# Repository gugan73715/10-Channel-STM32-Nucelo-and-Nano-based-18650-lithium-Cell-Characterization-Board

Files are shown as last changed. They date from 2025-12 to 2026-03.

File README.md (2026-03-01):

# Cell Characterization Board V1.2
This project is a 10-channel sequential lithium-ion cell (18650) characterization instrument designed to measure cell voltage, discharge current, internal resistance, and capacity under a controlled constant-current load of up to 5 A. The Cell data would be displayed on an LCD and stored on a MicroSD card which can be used to plot discharge curves using Excel/Matlab/Python. Protection features include Reverse Polarity Protection for each channel, Low voltage cut-off and hardware controlled sequential switching circuit with hardware interlock to create mutually exclusive channels.

V1.2 serves as a validation vehicle for the custom analog front-end and discharge bus, utilizing a modular MCU architecture (Nucleo/Nano) to minimize BOM and assembly costs as well as accelerate testing. Planned V2 would be an integrated STM32G0B1CCT6 based revision with a SPI TFT display.

## Primary Use Case

This system is designed to characterize and screen individual lithium-ion cells prior to adding it into a battery pack for UBC Rocket's Cloudburst rocket. This allows to exclude defective, mismatched, or degraded cells before battery pack assembly. It also helps prevent cell imbalance in series strings, individual cells overheating during discharge and reduced pack capacity due to lower cell capacity. This device could also be used in other projects involving high-energy battery systems such as Student Formula SAE electric vehicles, solar car teams, and any project requiring testing and characterization of large numbers of lithium-ion cells prior to pack assembly. 

## Key design goals
- Programmable constant-current discharge
- Accurate, ratiometric voltage and current measurement
- Fault-tolerant handling of reverse polarity and missing cells
- Sequential testing to minimize BOM cost and thermal complexity
- Hardware based protection features for reliability
- Reduce manufacturing and assembly cost as much as possible due to budget constraint
- Rapid bring up
- Clear documentation of design intent and constraints
  
# PCB Design:
## Latest 3D Render:
Cell Characterization Board V1 2 3D Render - Top
Cell Characterization Board V1 2 3D Render - Bottom
## V1.2:


## System Validation & Discharge Data:
CELL ID 3
Full discharge curve of a Sony VTC4 cell generated using the cell data from V1.2 10-channel tester, ploted using MATLAB. The system maintained a stable 1.5A constant current discharge, yielding a capacity measurement that matched the manufacturer's datasheet within 5% and a DCIR of 33mohm. This data confirms the precision of the op-amp control loop over a full discharge cycle and MOSFET maintained a approximate 45-50C temperature.

## Overview:
The system is implemented on a custom 4-layer mixed-signal PCB (SIG / GND / PWR / SIG) optimized for high-current power handling, precision analog measurement and noise handling. GND and PWR plane are continuous and unbroken providing low-impedance return paths and a stable reference plane. Proper zoning (Analog/Digital/Power) based component placement for noise immunity and short traces. Cell holders and relays are placed on both sides to decrease PCB size which helps reduce PCB manufacturing cost.
### High-Current Routing
- All >2 A paths use wide copper pours with stitching vias if possible to distribute the current
- All high current paths are kept as far away as possible from sensitive analog traces

### Analog Integrity
- All analog traces are on top layer with a GND plane below them
- Analog traces are kept as short as possible
- Important analog signals are buffered and have a decoupling capacitor close to it
- Quasi-Kelvin sense (Separate PWR and SIG traces but shared GND) is used for current and voltage measurement
  
### Noise and Protection
- Relay drive and switching currents are physically separated from the analog front-end
- External flyback diodes placed adjacent to each relay
- Relay coil and Flyback traces are kept as short as possible and fanned out to prevent noise from adjacent traces
- Decoupling capacitors placed close to each IC supply pin
- Reverse polarity protection for each channel using P-channel MOSFETs
- V_Cell traces are connected straight to cell holder for Quasi-kelvin sense and current limiting resistor on each trace to protect the MUX in case of reverse polarity.
- NTC on Load MOSFET's heatsink for active over temperature protection
- 30 ms Soft start for BUCK IC to prevent overshoot and inrush current

### Debugging
- Testpoints for 5V, 3.3V, 2.5V ref, GND, I_set, Constant Current op-amp feedback line, MOSFET Gate and I_sense.
- External UART, SPI and I2C headers for logic analysis
- MUX-out(Cell voltage) is accessible through MCU header

### Assembly & Cost Optimization
- 5 channels were placed on top and bottom to reduce PCB size and save fabrication costs
- Passive components are assembled by fabrication house and all of them have been placed on top for one sided assembly
- Active ICs, cell holders and connectors are hand-assembled post-fabrication to reduce assembly cost while retaining full control over critical components

# Hardware
08e247f1-ca4d-435c-84c2-786f73447f0c-0

## System Architecture Summary (Click subsection header for schematic sheet)
<details>
<summary><h3>Buck and LDO</h3></summary>
  
Buck and LDO Schematic (https://github.com/user-attachments/assets/7cbbd1c2-d676-4704-b09d-97c5c336276e)
</details>

- input DC Jack / XT60: 8–40 V
- input USB-C: 5V 3A (Non-PD)
- 5 V logic rail via AP64502QSP-13 based synchronous buck converter
- Dedicated 3.3 V LDO for MicroSD and SPI

<details>
<summary><h3>Constant Current Sink</h3></summary>
  
Constant Current Sink (https://github.com/user-attachments/assets/1adb6a28-354b-4ce8-b8a3-19815ae03084)
</details>

- IRLZ44N Logic level MOSFET and TLV9162 control op-amp
- Low side 50mohm 3W shunt
- DAC60501ZDGSR 12-bit DAC for precise control of discharge current and controlled via I2C
- Internal 2.5 V precision reference of DAC is shared by ADC as well
- Amplified I_sense signal (0 - 2.5V) using MCP6001 for better resolution
- Theoretical MOSFET temperature with heat sink (θ_normal = 2.6 C/W) at max case (5A) is 115.86 C (Assuming 25 C ambient)
- Load MOSFET temperature monitoring via NTC
- Maximum discharge current: 5 A

<details>
<summary><h3>MCU</h3></summary>

MCU (https://github.com/user-attachments/assets/0a89f7f0-6815-4320-b8e9-275b107875d0)

</details>

- Compatible with 3.3V STM32 Nucleo boards with nano connectivity like NUCLEO-L432KC and Arduino nano
- External I2C header for debugging and future expansion modules
- External UART header for telemetry

<details>
<summary><h3>Cell Holder</h3></summary>

Cell Holder (https://github.com/user-attachments/assets/d6683df6-3a02-4f7b-97c8-28835414f6b9)

</details>

- DIY 3D printed SMD 18650 cell holders (similar to Keystone 1043) with 0.2mm nickel strips as cell contacts to save BOM cost
- Reverse polarity protection for each channel using MCQ7328-TP P-channel MOSFETs
- Cell voltage sense traces are connected straight to cell holder pads for quasi-kelvin sense

<details>
<summary><h3>Sequential Cell Switching</h3></summary>

Sequential Cell Switching (https://github.com/user-attachments/assets/1cc9c982-065a-40d1-963c-5ec4ebc452d4)

</details>

- Control Logic: MCU -> I2C Expander -> Line Decoder (For mutually exclusive channels) -> Relay Driver -> Relay -> Cell Holder
- Relay-based physical isolation of cells driven by darlington transistor array on High side
- PCF8575PWR I2C expander for I/O expansion
- CD4514BM96 decoder to prevent connecting more than one channel at the same time and an active high inhibit pin controlled by I2C expander
- External pull ups on all I2C lines and external flyback diodes on all relays

<details>
<summary><h3>Cell Monitoring</h3></summary>

Cell Monitoring (https://github.com/user-attachments/assets/edf4d94d-06c7-463c-b50f-4eb45057faaf)

</details>

- CD74HC4067SM96 16:1 analog MUX for cell voltage sampling
- MUX out is converted to a signal of 0 to 2.5V using a voltage divider and then buffered
- Current limiting resistor(limits to 2.1mA) on each channel to protect the MUX in case of reverse polarity (MUX's internal ESD clamp diode forward biases)

<details>
<summary><h3>MicroSD</h3></summary>

MicroSD (https://github.com/user-attachments/assets/78fb6a4d-2293-464c-a3f9-e3ed3d292f46)

</details>

- Data is written to MicroSD using SPI
- TXU0304PWR unidirectional voltage level translator for 5V to 3.3V for SCK, MOSI, CS (MCU to MicroSD) and 3.3V to 5V for MISO (MicroSD to MCU)
- SD detect LED for user-friendliness
- Parameters: Time, Cell Voltage, Discharge Current, Internal Resistance, I_set, Cut-off voltage and capacity (mAh / Wh)
- Internal Resistance is calculated using r = (V_OC - V_sense)/I. (Voltage drop across cell under a load)

## Prototyping and Validation:

### LTspice simulation: (Constant Current Sink)



### Breadboard prototyping:


- Constant current sink prototype built using IRL510 + LM158J
- Shunt resistor: 1.5 Ω / 5 W
- Gate and feedback resistors as implemented in hardware
- 0.5V out DAC emulated via resistive divider from 5 V
- Load driven by a current-limited (For safety) bench supply (2.5 V–4.2 V sweep)

Measured discharge current remained approximately constant (~340 mA) across the full input voltage range.

# Firmware

- Initial firmware developed using Arduino IDE for rapid bring-up
- Secondary firmware under development using STM32CubeIDE with STM32HAL and testing using an NUCLEO-G431KB

### Objectives:

- Validation of the sequential switching mechanism to guarantee mutual exclusivity of active channels
- Cell voltage sampling verification across all channels using the MUX
- Verify ADC and DAC resolution using the shared 2.5 V reference
- Validation of current measurement accuracy and stability across the full discharge range

# Planned Revision (V2):

- Transitioning to a STM32G0B1CCT6 onboard MCU
- Switching to SPI-based TFT display for real-time visualization
- Switching to Zero-drift, ultra-low-offset op-amp for better accuracy
- NTC on each channel for cell temperature monitoring
- Short-circuit and overtemperature protection for each channel 
- Firmware detection of protection features and informing the user
- Audible and visual fault and status indication (buzzer and status LEDs)

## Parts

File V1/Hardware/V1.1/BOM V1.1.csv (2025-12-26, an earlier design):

Line # | Name | Description | Designator | Quantity | Manufacturer 1 | Manufacturer Part Number 1 | Manufacturer Lifecycle 1 | Supplier 1 | Supplier Part Number 1 | Supplier Unit Price 1 | Supplier Subtotal 1
 | AP64502QSP-13 | Description | BUCK IC | 1 | Diodes Inc. | AP64502QSP-13 | Volume Production | Mouser | 621-AP64502QSP-13 | 3.56 | 3.56
 | CC0603KPX7R9BB104 | CAP CER 0.1UF 50V X7R 0603 | C1, C2, C3, C4, C12, C14, C15, C16, C17, C18, C19, C20 | 11 | Yageo Group | CC0603KPX7R9BB104 | Volume Production | Mouser | 603-CC603KPX7R9BB104 | 0.03796 | 0.41751
 | EEE-FT1H221GP | CAP ALUM 220UF 20% 50V SMD | C5 | 1 | Panasonic | EEE-FT1H221GP | Unknown | Arrow Electronics | EEE-FT1H221GP | 0.44956 | 0.44956
 | GRM155R61H474KE11D | Chip Multilayer Ceramic Capacitors for General Purpose, 0402, 0.47uF, X5R, 15%, 10%, 50V | C6, C7, C8, C9 | 4 | Murata | GRM155R61H474KE11D | Volume Production | Mouser | 81-GRM155R61H474KE1D | 0.05061 | 0.50607
 | CL31A106KBHNNNE | CAP CER 10UF 50V X5R 1206 | C10, C11 | 2 | Samsung Electro-Mechanics | CL31A106KBHNNNE | Volume Production | DigiKey | 1276-2876-6-ND | 0.12652 | 0.25304
 | C0402C103J3RACAUTO | C0402 10,000 pF X7R 5.00% 25 V | C13 | 1 | KEMET | C0402C103J3RACAUTO | Volume Production | Mouser | 80-C0402C103J3RAUTO | 0.14058 | 0.14058
 | S1M-13-F | Surface Mount Glass Passivated Rectifier, 1000V, 1 A, -65 to 125 degC, 2-Pin SMA Package, RoHS, Tape and Reel | D1, D2, D3, D4, D5, D6, D7, D8, D9, D10 | 10 | Diodes Inc. | S1M-13-F | Volume Production | DigiKey | S1M-FDIDKR-ND | 0.15604 | 1.56
 | DAC60501ZDGSR | True 12-bit, 1-ch, SPI/I2C, voltage-output DAC in WSON package with precision internal reference 10-VSSOP -40 to 125 | DAC | 1 | Texas Instruments | DAC60501ZDGSR | Volume Production | DigiKey | 296-DAC60501ZDGSRCT-ND | 3.77 | 3.77
 | PJ-102BH | Through Hole Right Angle DC Power Jack, 5 A, 2.5 mm Center Pin, 3 Position, -25 to 85 degC, RoHS, Bulk | DC JACK - IN | 1 | Same Sky | PJ-102BH | Volume Production
 | 74279252 |  | FB1 | 1 | Wurth Elektronik | 74279252 | Unknown | Mouser | 710-74279252 | 0.42173 | 0.42173
 | PCF8575PWR | Remote 16-Bit I2C and SMBus I/O Expander with Interrupt Output, 2.5 to 5.5 V, -40 to 85 degC, 24-pin TSSOP (PW), Green (RoHS & no Sb/Br) | I2C EXPANDER | 1 | Texas Instruments | PCF8575PWR | Volume Production | Arrow Electronics | PCF8575PWR | 1.59 | 1.59
 | TSW-104-23-T-S | CONN HEADER VERT 4POS 2.54MM | I2C, UART | 2 | Samtec | TSW-104-23-T-S | Volume Production | Avnet | TSW-104-23-T-S | 0.4684 | 0.9368
 | MGAH06036R8M-10 | 6.8 ÂµH Shielded Molded Inductor 5 A 50mOhm Max Nonstandard | L1 | 1 | Laird | MGAH06036R8M-10 | Volume Production | Mouser | 739-MGAH06036R8M-10 | 0.63259 | 0.63259
 | IRLZ44NPbF | MOSFET N-CH 55V 47A TO220AB | MOSFET_CC | 1 | Infineon | IRLZ44NPBF | Volume Production | Arrow Electronics | IRLZ44NPBF | 1.97 | 1.97
 | CD74HC4067SM96 | IC MUX/DEMUX 1X16 24SSOP | MUX | 1 | Texas Instruments | CD74HC4067SM96 | Volume Production | Mouser | 595-CD74HC4067SM96 | 0.88563 | 0.88563
 | NXRT15XH103FA1B030 | Thermistor NTC 10kΩ ±1% 2-Pin Radial Bulk | NTC | 1 | Murata | NXRT15XH103FA1B030 | End of Life | Arrow Electronics | NXRT15XH103FA1B030 | 0.19371 | 0.19371
 | TLV9162IDDFR | Dual, 16V, 11MHz, rail-to-rail input and output low-offset-voltage low-noise operational amplifier | OA CC SINK, OA UB 1 | 2 | Texas Instruments | TLV9162IDDFR | Volume Production | Mouser | 595-TLV9162IDDFR | 2.78 | 5.57
 | MCP6001UT-E/OT | None | OA I_SENSE, OA UB 2 | 2 | Microchip | MCP6001UT-E/OT | Volume Production | Farnell | 1840893 | 0.47585 | 0.95169
 | 2K2 5% 0402(1005) | 2K2 0.063W 5% 0402 (1005 Metric) SMD | R1 | 1 | Bourns | CR0402-JW-222GLF | Volume Production | Farnell | 4153652 | 0.00772 | 0.07716
 | 1K3 5% 2512(6432) | 1K3 1W 5% 2512 (6432 Metric) SMD | R2 | 1 | Vishay | CRCW25121K30JNEG | Volume Production | Arrow Electronics | CRCW25121K30JNEG | 0.16757 | 0.16757
 | CPF0603B10K7E | RES SMD 10.7KΩ 0.1% 1/16W 0603 | R3, R4 | 2 | TE Connectivity / AMP | 1-1879220-2 | Volume Production | Mouser | 279-CPF0603B10K7E | 0.43579 | 0.87157
 | Resistor 4k7 +/-1% 0402 100 mW | Chip Resistor, 4.7 KOhm, +/- 1%, 0.1 W, -55 to 155 degC, 0402 (1005 Metric) | R5, R8, RPU1, RPU2, RPU3, RPU4, RPU5, RPU6, RPU7, RPU8, RPU9, RPU10 | 12 | Panasonic | ERJ-2RKF4701X | Volume Production | Newark | ERJ2RKF4701X | 0.025 | 0.3
 | 523K 1% 0805(2012) | 523K 0.125W 1% 0805 (2012 Metric) SMD | R6 | 1 | Vishay | CRCW0805523KFKEA | Volume Production | Arrow Electronics | CRCW0805523KFKEA | 0.00295 | 0.00295
 | CRCW1210220RJNTA |  | R7 | 1 | Vishay | CRCW1210220RJNTA | Volume Production | Mouser | 71-CRCW1210J-220 | 0.5623 | 0.5623
 | AC0603JR-7W10KL | RES 10kΩ 5.00% 0.2W 0603 | R9, R11, R12 | 3 | Yageo Group | AC0603JR-7W10KL | Volume Production | Mouser | 603-AC0603JR-7W10KL | 0.0253 | 0.25304
 | 7K5 1% 2010(5025) | 7K5 0.75W 1% 2010 (5025 Metric) SMD | R10 | 1 | Vishay | CRCW20107K50FKEF | Volume Production | Arrow Electronics | CRCW20107K50FKEF | 0.0388 | 0.0388
 | RNCP1206FTD100R | 100Ω ±1% 0.5W 1206 High Power Anti-Sulfur Thin Film Chip Resistor | R13, R15 | 2 | Stackpole Electronics | RNCP1206FTD100R | Volume Production | Mouser | 708-RNCP1206FTD100R | 0.02249 | 0.22492
 | CRCW251218K0FKEG | RES Thick Film, 18kΩ, 1%, 1W, 100ppm/°C, 2512 | R14 | 1 | Vishay | CRCW251218K0FKEG | Volume Production
 | 10K2 1% 0402(1005) | 10K2 0.063W 1% 0402 (1005 Metric) SMD | R16 | 1 | Panasonic | ERJ-2RKF1022X | Volume Production | Avnet | 53W4182 | 0.13776 | 0.13776
 | RN73R1ETTP2001F25 | 2kΩ ±1% 0.063W, 1/16W Chip Resistor 0402 (1005 Metric) Moisture Resistant Thin Film | R17 | 1 | KOA Speer | RN73R1ETTP2001F25 | Volume Production
 | 1K2 1% 1812(4532) | 1K2 0.75W 1% 1812 (4532 Metric) SMD | R18 | 1 | Vishay | CRCW12181K20FKTK | Volume Production | Mouser | 71-CRCW12181K20FKTK | 1.17 | 1.17
 | G5LE-1A DC5 | RELAY GEN PURPOSE SPST 10A 5V | RELAY 1, RELAY 2, RELAY 3, RELAY 4, RELAY 5, RELAY 6, RELAY 7, RELAY 8, RELAY 9, RELAY 10 | 10 | Omron | G5LE-1A DC5 | Volume Production | DigiKey | Z3115-ND | 1.32 | 13.16
 | ULN2003V12DR | MOSFET 7CH 16SOIC | RELAY DRIVER 1, RELAY DRIVER 2 | 2 | Texas Instruments | ULN2003V12DR | Volume Production | DigiKey | 296-30538-1-ND | 1.55 | 3.09
 | TSW-106-07-G-S | 0.025" SQ Post Header, Through-hole, Vertical, -55 to 125 degC, 2.54 mm Pitch, 6-Pin, Male, RoHS | SD Card Module, SPI | 2 | Samtec | TSW-106-07-G-S | Volume Production | Avnet | TSW-106-07-G-S | 0.62821 | 1.26
 | CRA2512-FZ-R050ELF | RES 0.05 OHM 1% 3W 2512 | SHUNT | 1 | Bourns | CRA2512-FZ-R050ELF | Volume Production | DigiKey | CRA2512-FZ-R050ELFCT-ND | 0.77317 | 0.77317
 | USB4125-GF-A-0190 | CONN RCPT TYPE C 6P SMD RA | USB - C IN | 1 | Global Connector Technology | USB4125-GF-A-0190 | Volume Production | Newark | USB4125-GF-A-0190 | 0.54684 | 0.54684
 | XT60-M | Plug; DC supply; XT60; male; PIN: 2; for cable; soldered; 30A; 500V | XT60 | 1 | Amass | XT60-M | Unknown
 | MIC5504-3.3YM5-TR | IC REG LINEAR 3.3V 300MA SOT23-5 | 3.3V LDO | 1 | Microchip | MIC5504-3.3YM5-TR | Volume Production | Arrow Electronics | MIC5504-3.3YM5-TR | 0.1502 | 0.1502
 | LTST-C190GKT | LED GREEN CLEAR CHIP SMD | D11 | 1 | Lite-On | LTST-C190GKT | Not Recommended for New Design | Mouser | 859-LTST-C190GKT | 0.13 | 0.13
 | DM3AT-SF-PEJM5(40) | CONN MICRO SD R/A PUSH-PUSH SMD | MicroSD | 1 | HIROSE ELECTRIC | DM3AT-SF-PEJM5(40) | Volume Production | Mouser | 798-DM3AT-SF-PEJM540 | 2.94 | 2.94
 | CRCW1210120RJNTA |  | R19 | 1 | Vishay | CRCW1210120RJNTA | Volume Production

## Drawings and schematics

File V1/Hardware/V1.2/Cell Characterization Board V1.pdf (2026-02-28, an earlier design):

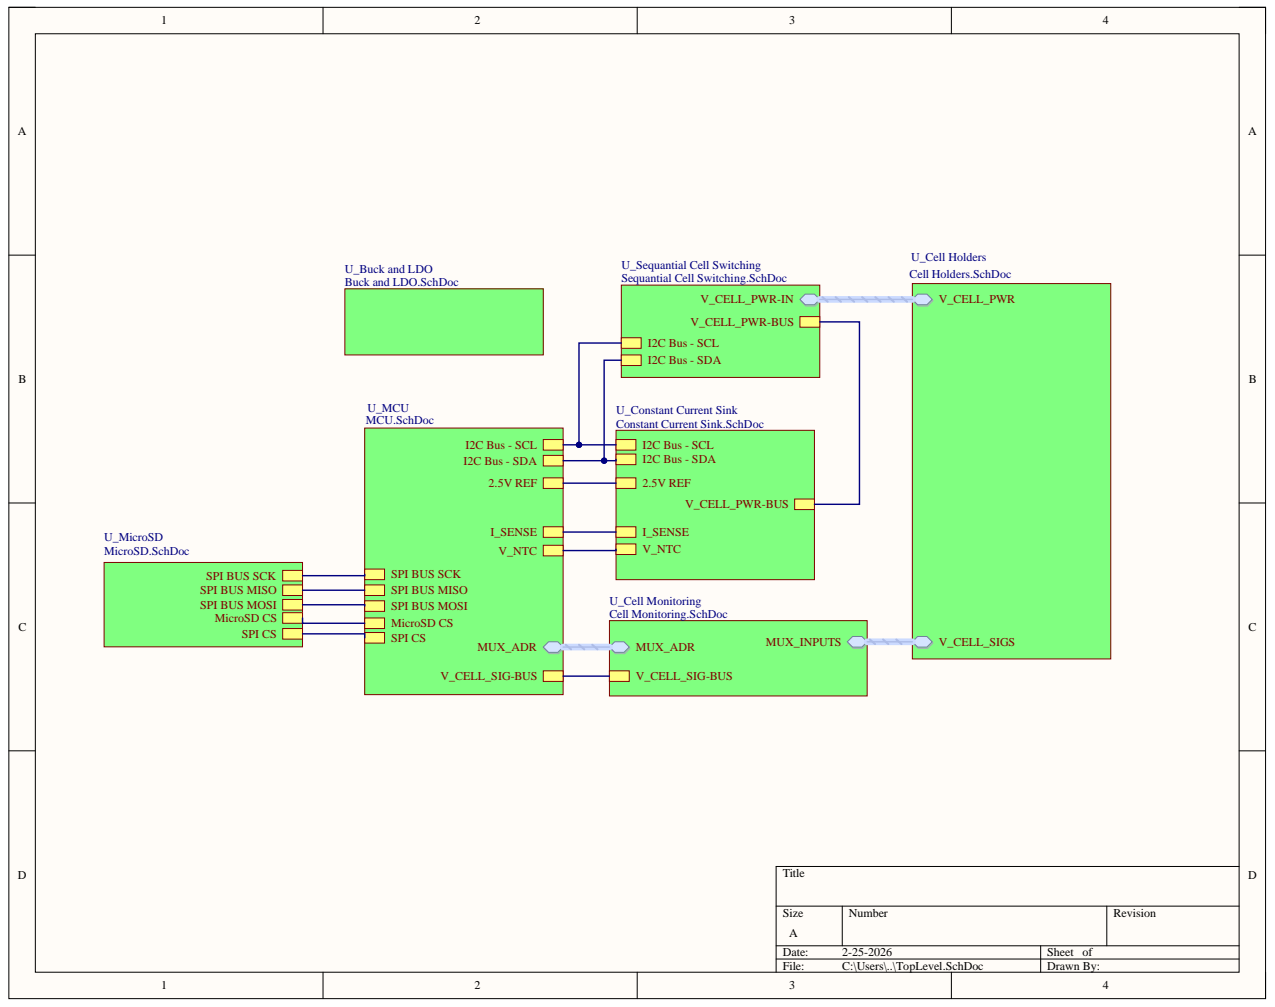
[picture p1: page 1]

U_Sequantial Cell Switching
Sequantial Cell Switching.SchDoc

U_Buck and LDO
Buck and LDO.SchDoc

U_Constant Current Sink
Constant Current Sink.SchDoc

Size A | Number | Revision

Date: 2-25-2026 | Sheet of
File: C:\Users\..\TopLevel.SchDoc | Drawn By:

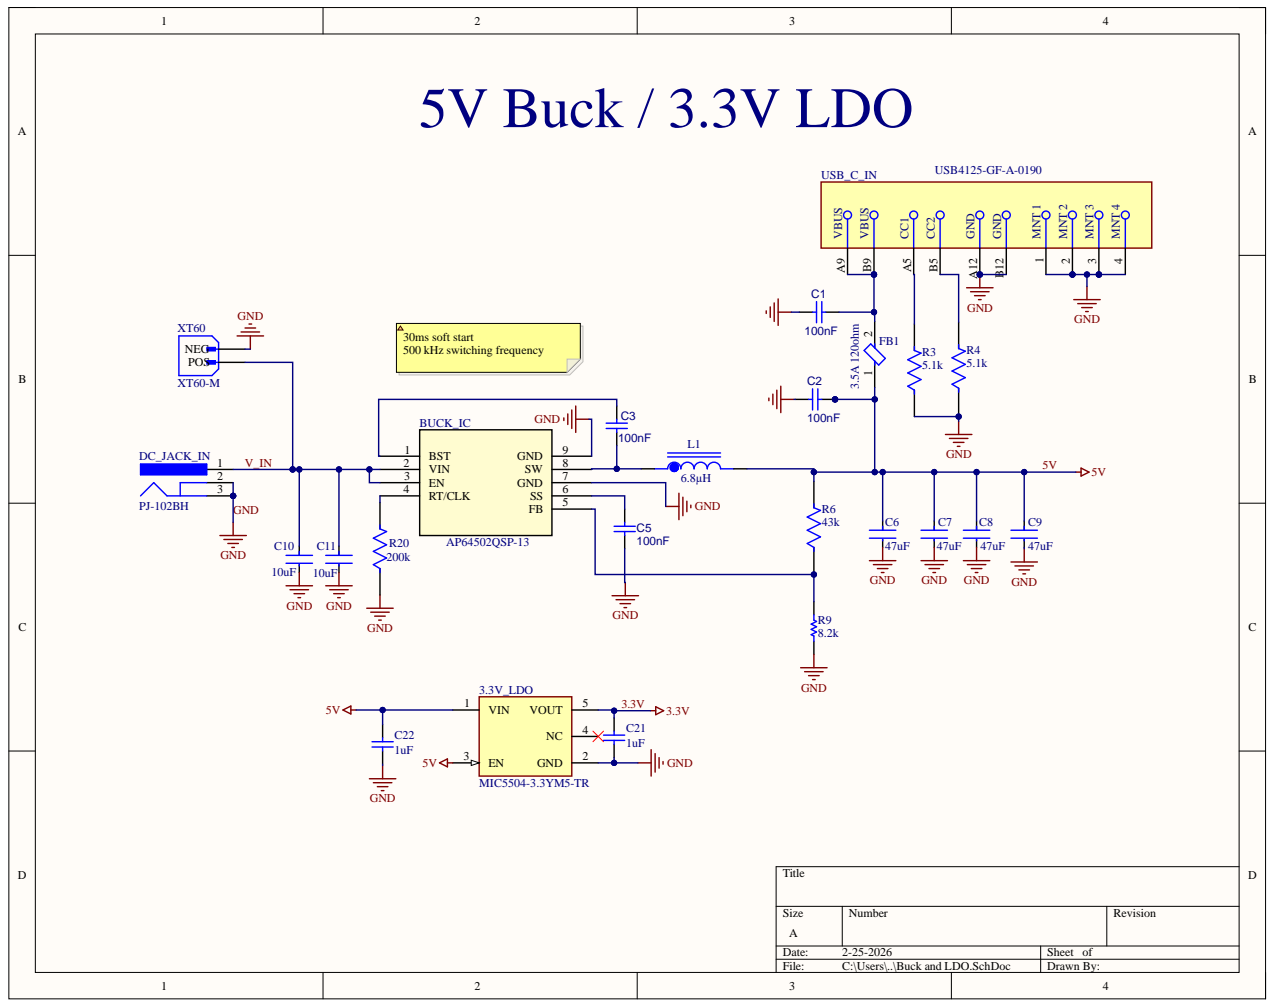
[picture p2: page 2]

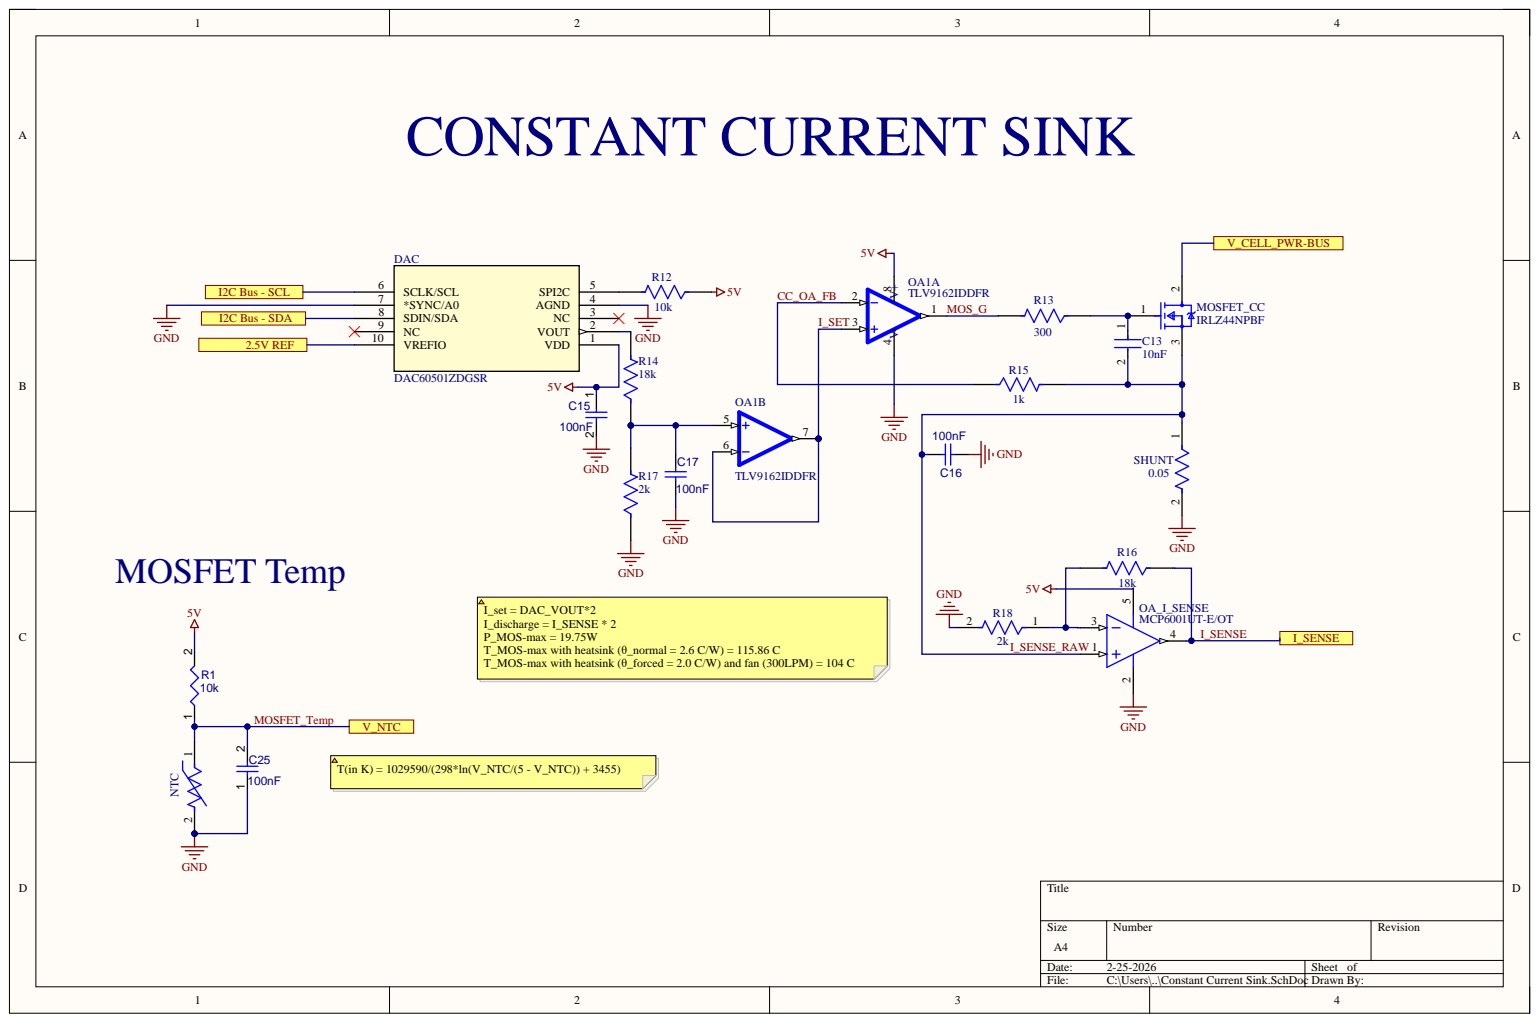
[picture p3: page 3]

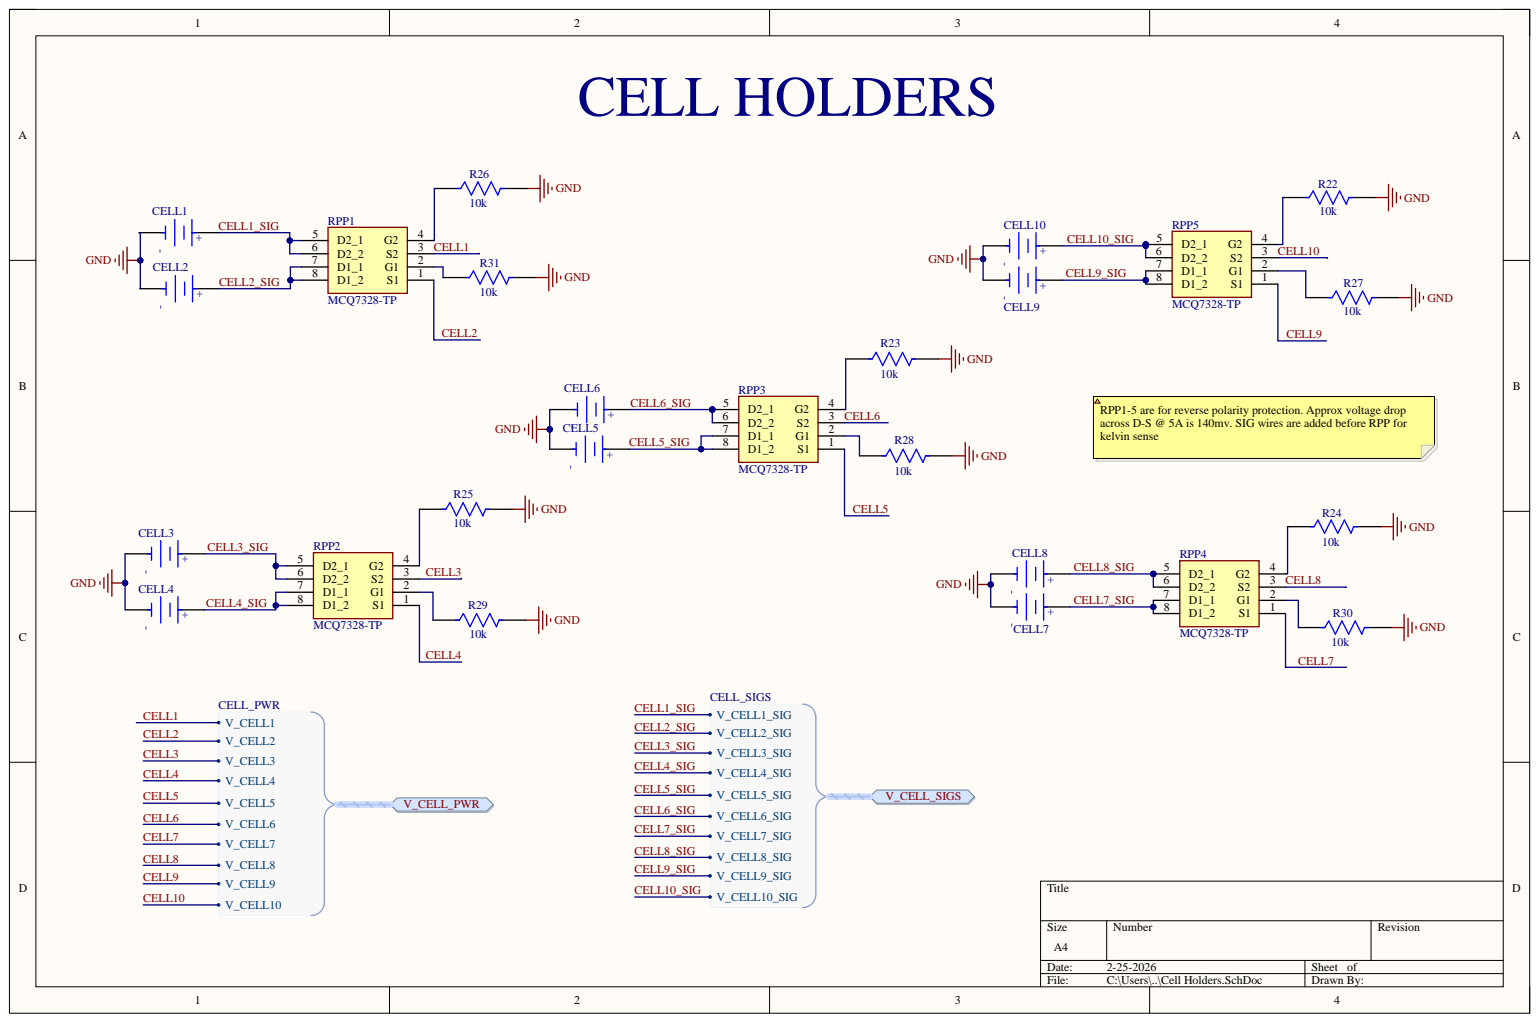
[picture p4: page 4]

RPP1-5 are for reverse polarity protection. Approx voltage drop
across D-S @ 5A is 140mv. SIG wires are added before RPP for
kelvin sense

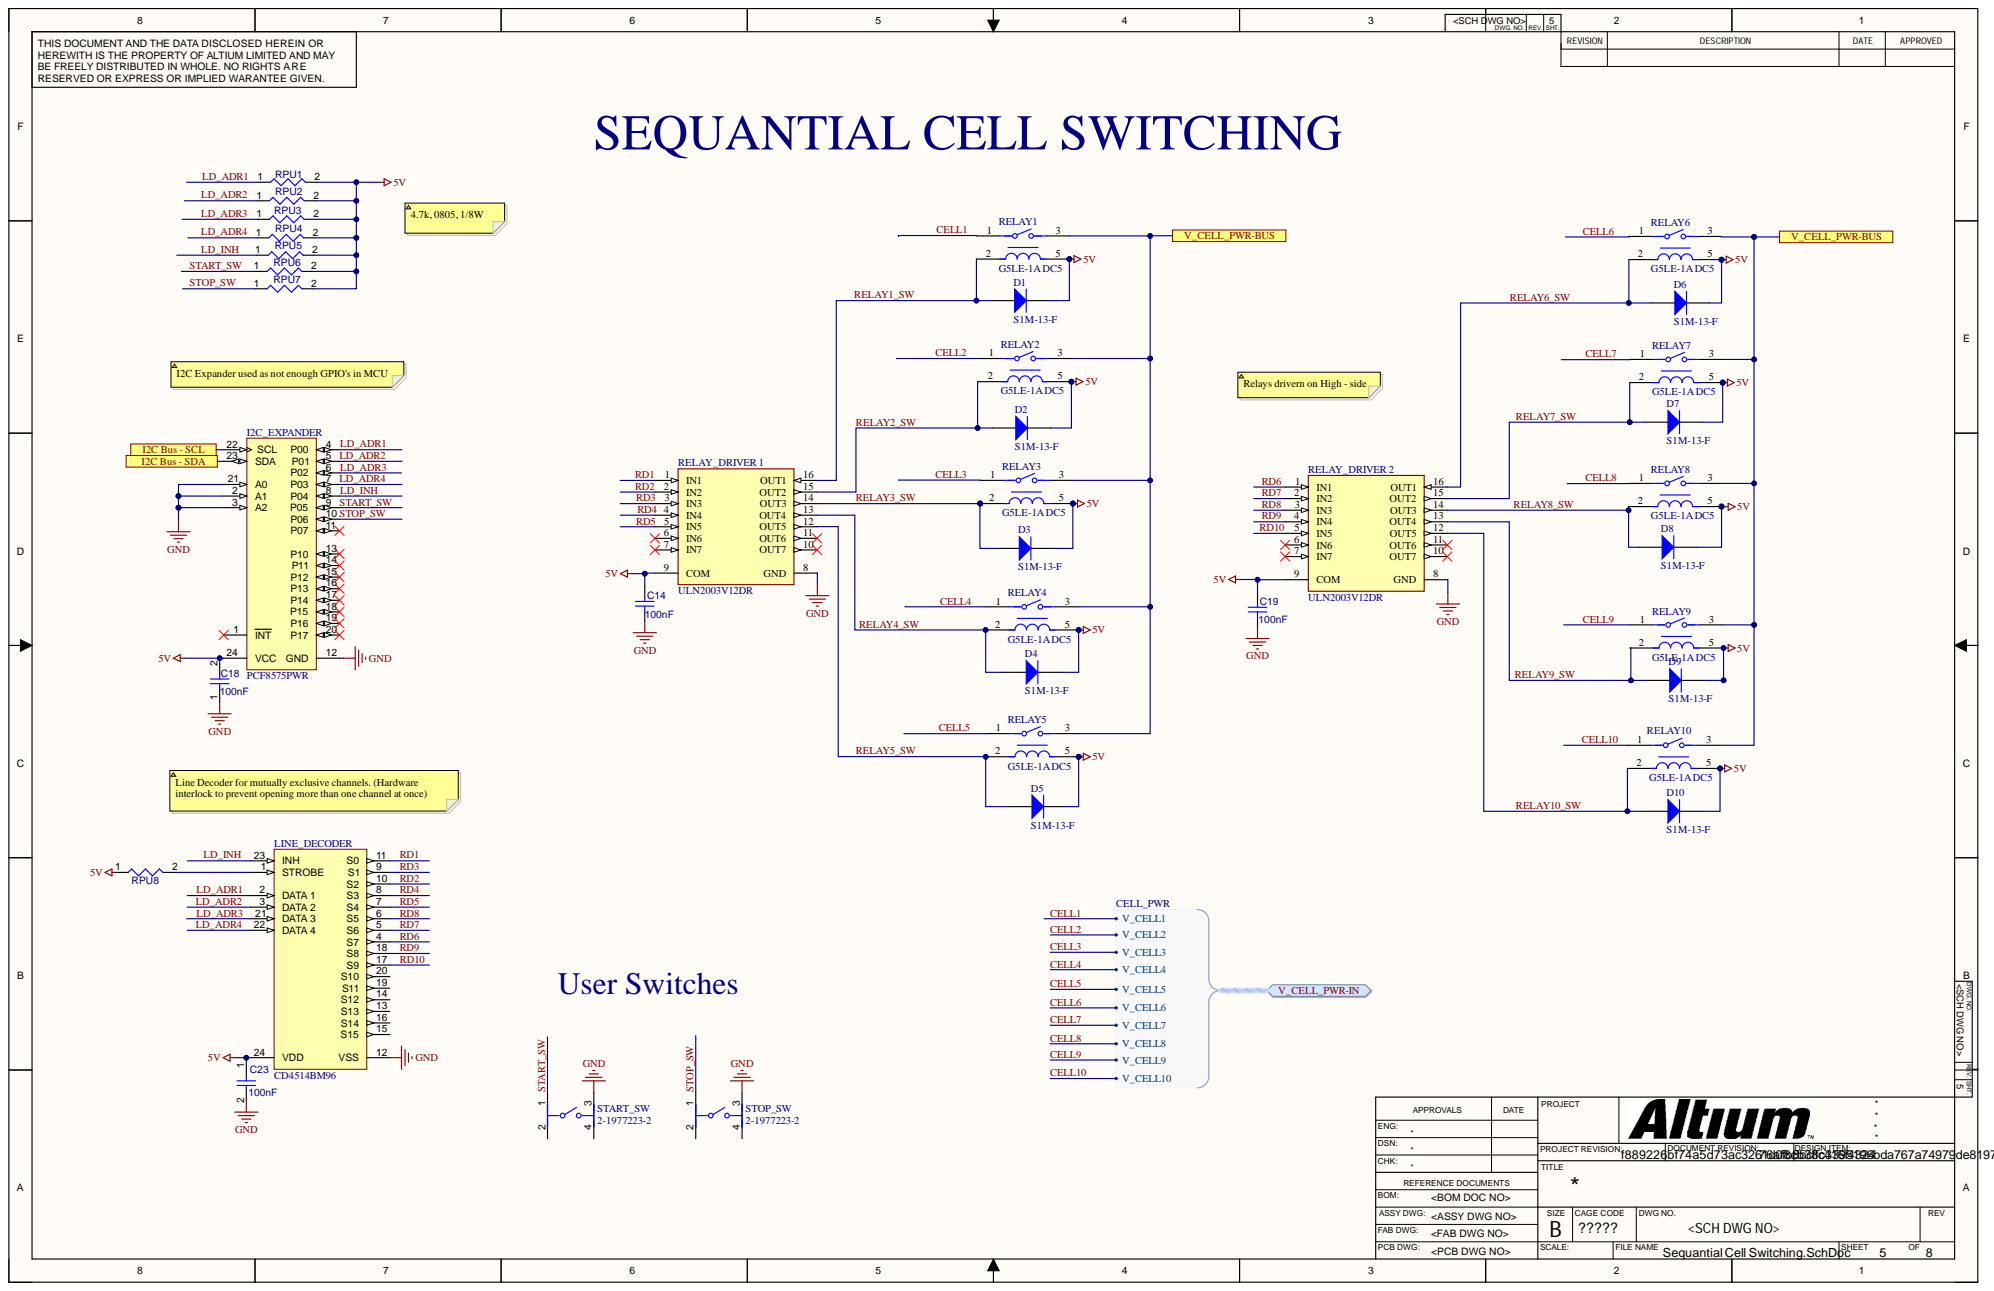
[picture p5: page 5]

DWG. NO. | REV. | SHT. <SCH DWG NO> 5

THIS DOCUMENT AND THE DATA DISCLOSED HEREIN OR HEREWITH IS THE PROPERTY OF ALTIUM LIMITED AND MAY BE FREELY DISTRIBUTED IN WHOLE. NO RIGHTS ARE RESERVED OR EXPRESS OR IMPLIED WARANTEE GIVEN. | | REVISION | DESCRIPTION | DATE | APPROVED

I2C Expander used as not enough GPIO's in MCU

Relays drivern on High - side

Line Decoder for mutually exclusive channels. (Hardware
interlock to prevent opening more than one channel at once)

REV. SHT. DWG. NO.

DATE | PROJECT | * * APPROVALS * *

ENG: *
CHK: * | | TITLE *

DSN: *

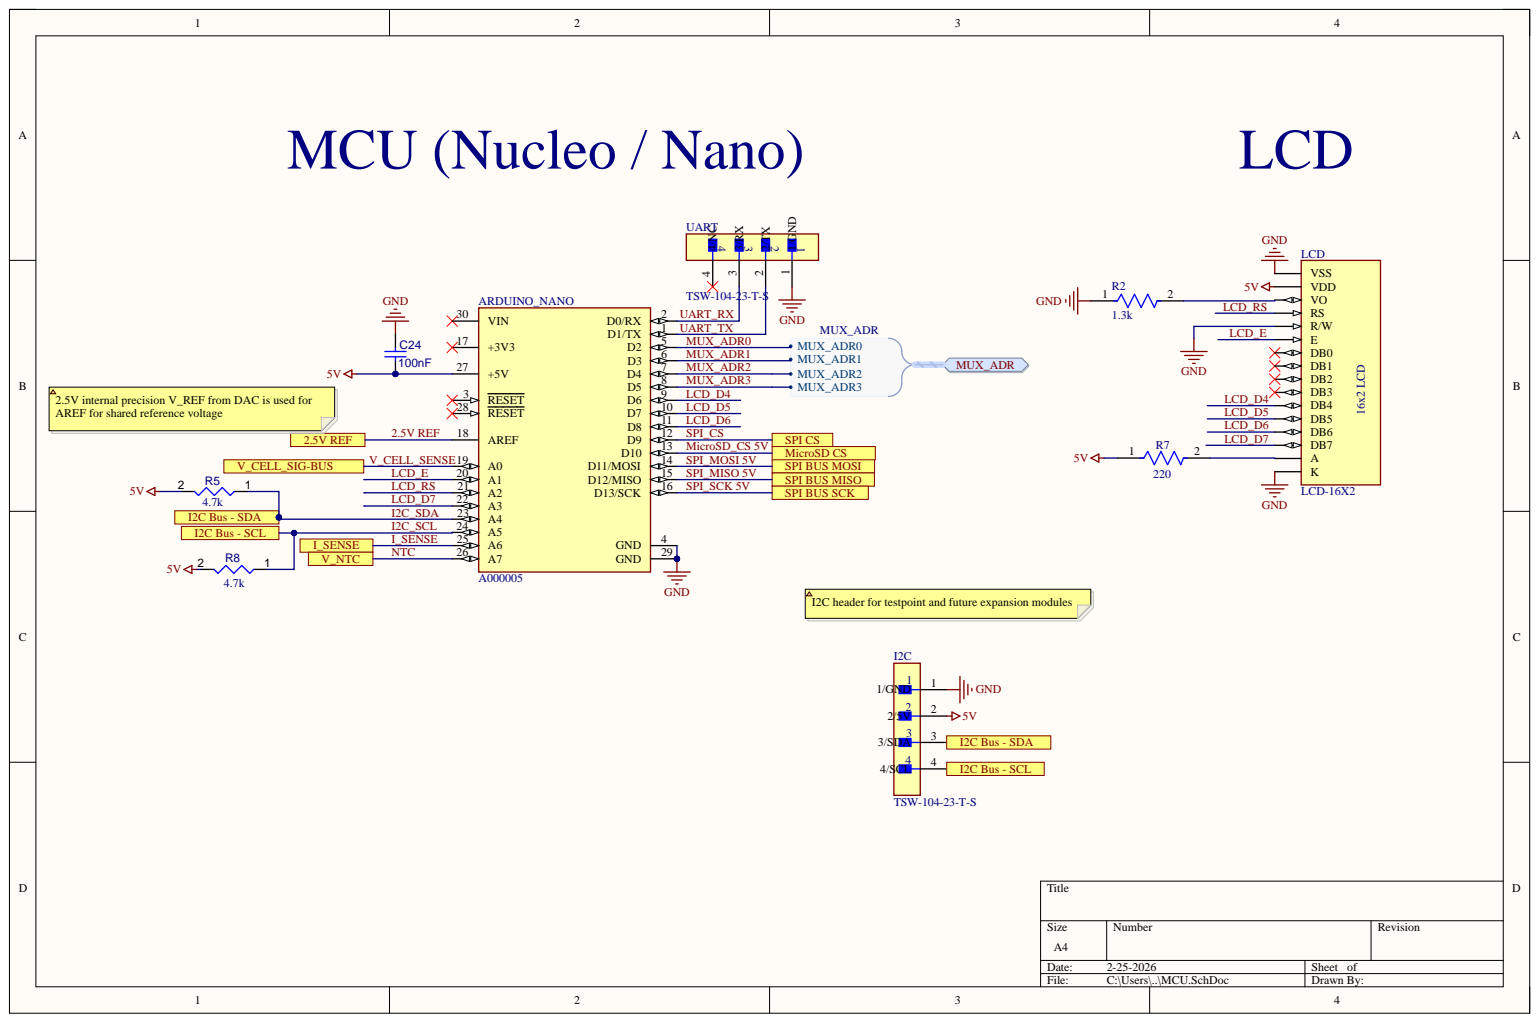
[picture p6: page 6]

TSW-104-23-T-S UART_RX

LCD_E

2.5V internal precision V_REF from DAC is used for
AREF for shared reference voltage

I2C header for testpoint and future expansion modules

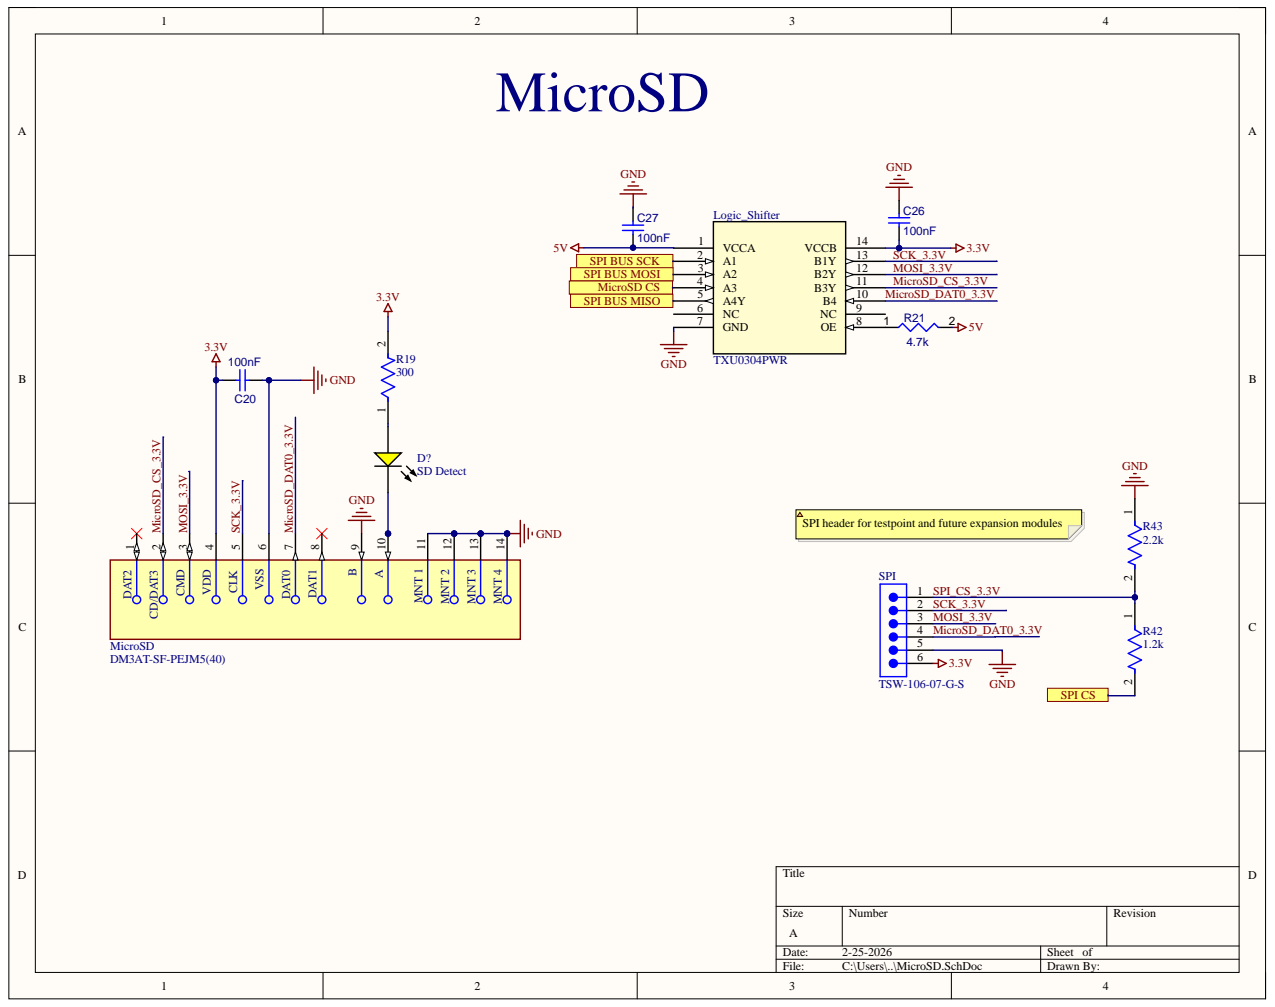
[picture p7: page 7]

SPI header for testpoint and future expansion modules

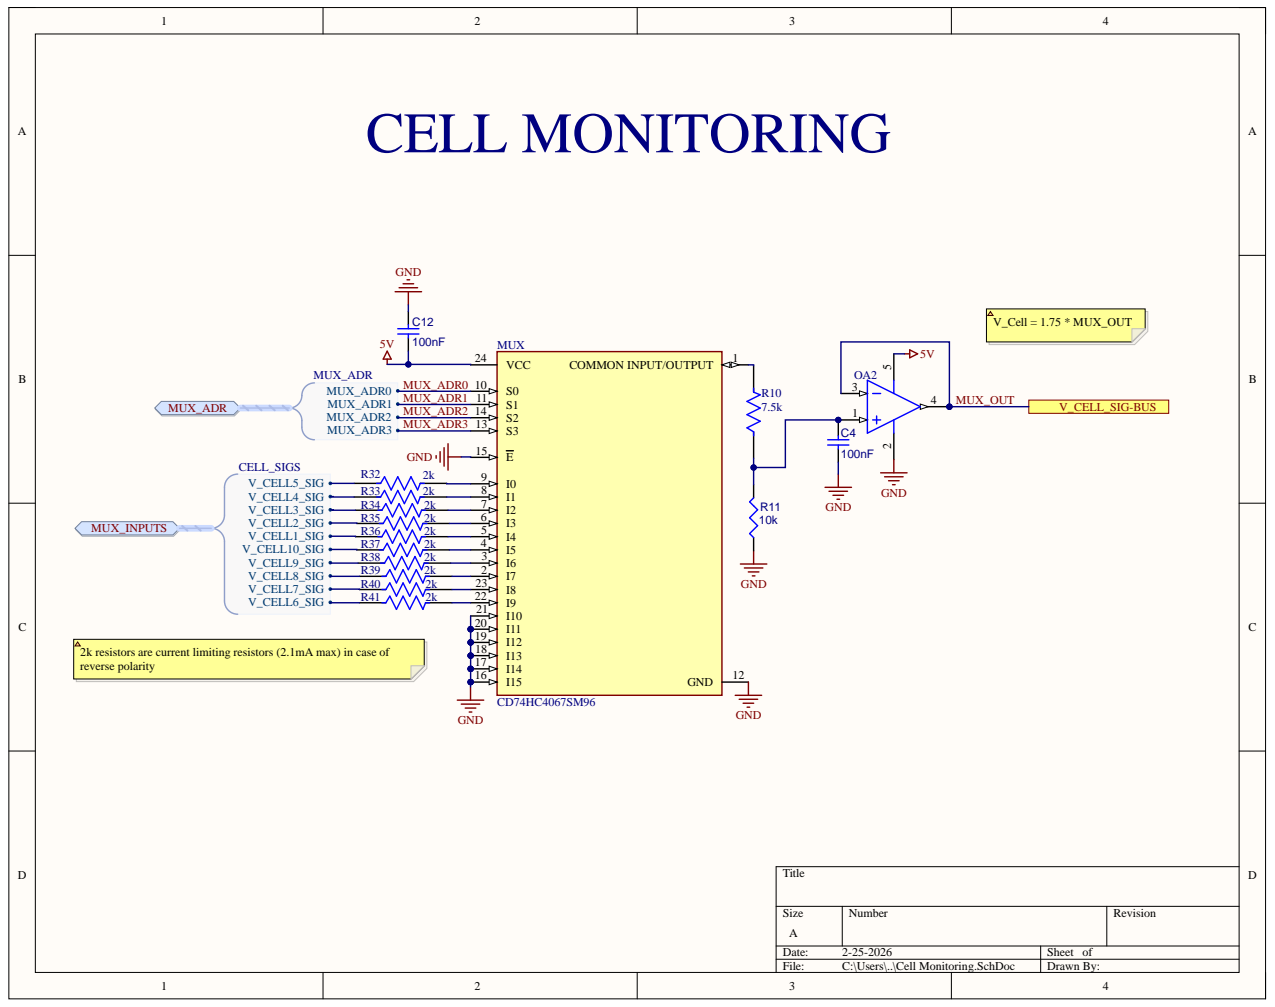
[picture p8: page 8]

2k resistors are current limiting resistors (2.1mA max) in case of
reverse polarity

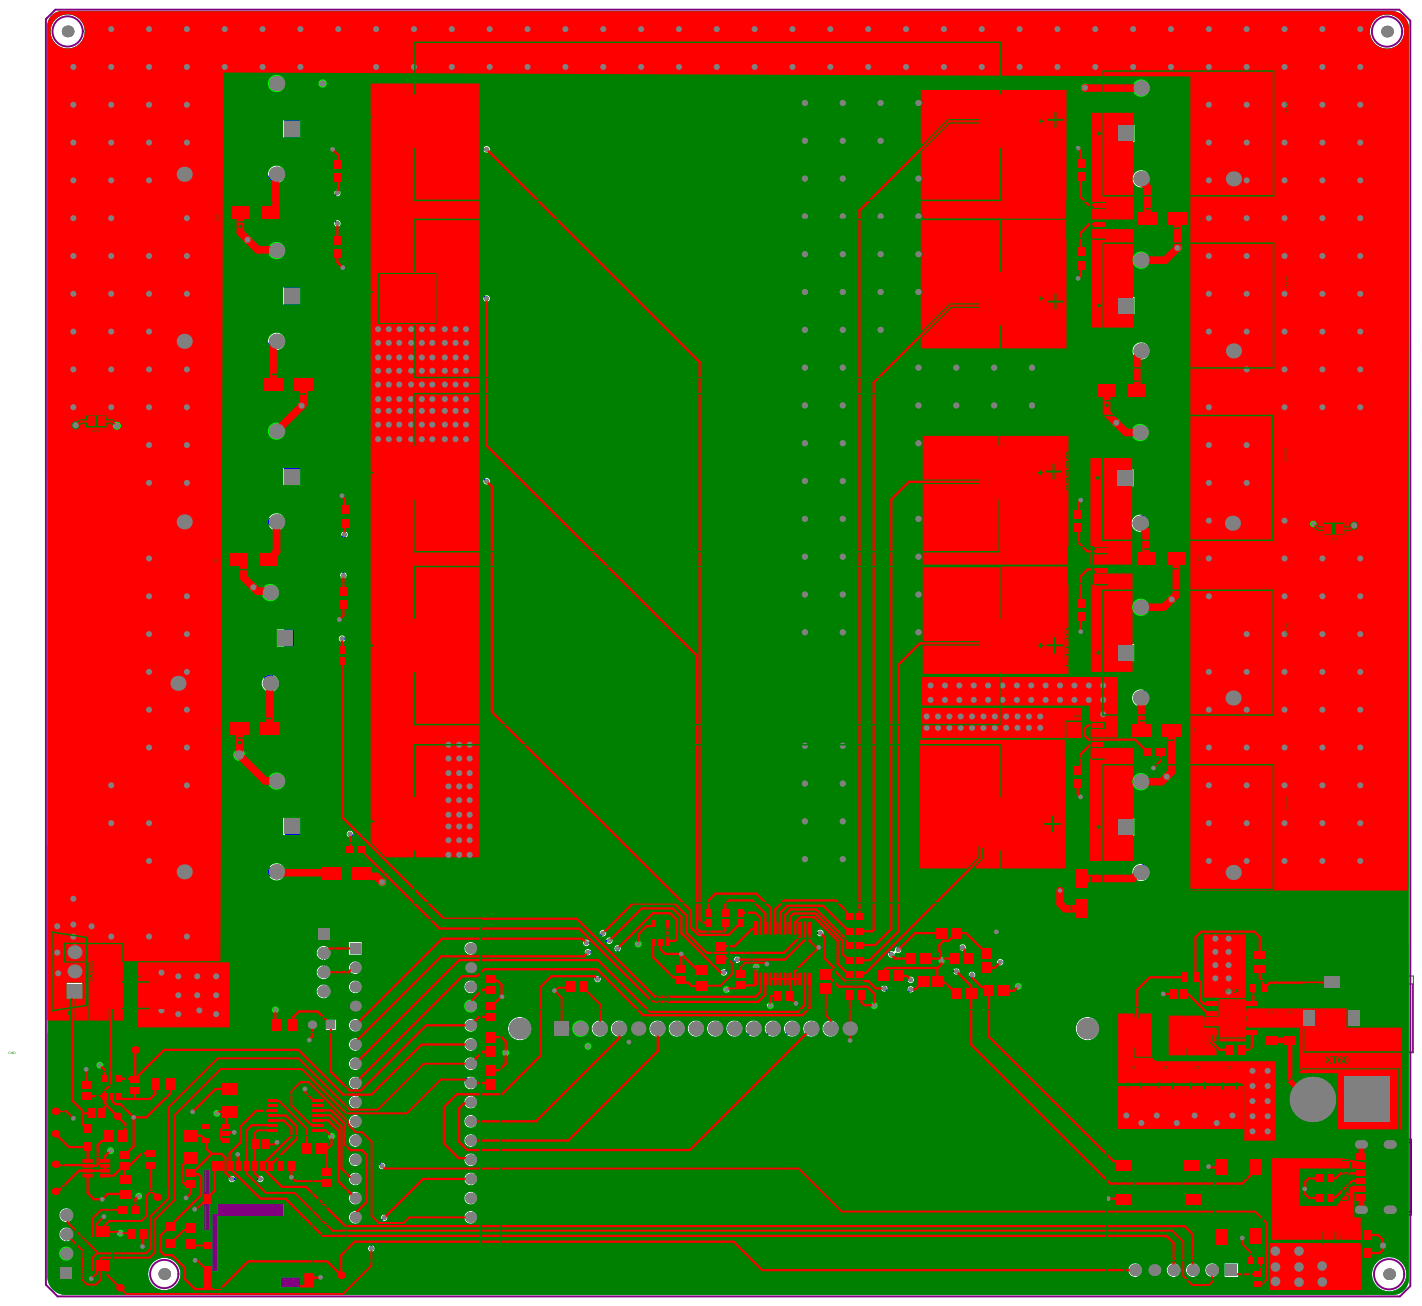
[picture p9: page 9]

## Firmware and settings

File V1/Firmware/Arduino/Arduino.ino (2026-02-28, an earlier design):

#include "GPIO.h"
#include <SPI.h>
#include <SD.h>

#include <LiquidCrystal.h>


// Initialize the library with the numbers of the interface pins:
// rs, en, d4, d5, d6, d7
// These pin numbers are common, but adjust them if you wired the LCD differently.
const int rs = 13, en = 11, d4 = 7, d5 = 8, d6 = 9, d7 = 10;
LiquidCrystal lcd(LCD_RS, LCD_EN, d4, d5, d6, d7);

// --- Variables to hold the data you want to display ---
// You would replace these with sensor readings or user inputs in a real application.
int cellNumber = 1;
float capacityAh = 0;
float currentSettingA = 0.5;

void setup() {

  // External 2.5V Reference From DAC
  analogReference(EXTERNAL);

  // Set up the number of columns and rows on the LCD (16 columns, 2 rows)
  lcd.begin(16, 2);
  
  // Print a brief message at startup
  lcd.print("System Initializing");
  delay(2000); // Wait 2 seconds
  lcd.clear(); // Clear the screen after the initial message
}

void loop() {
  // --- Line 1: Cell Number and Capacity ---
  
  // Set the cursor to the first column (0) of the first row (0)
  lcd.setCursor(0, 0); 
  
  // Print "Cell no. :"
  lcd.print("Cellno.");
  
  // Move the cursor to where the value should go (column 10, row 0)
  lcd.setCursor(7, 0); 
  
  // Print the value of the cell number
  lcd.print(cellNumber); 
  lcd.print(" ");

  // Move the cursor a bit further to the right (column 12, row 0)
  lcd.setCursor(9, 0);
  
  // This is a space saver. If the cell number is single digit, we start Capacity on the same line.
  // Print "Cap:" (shortened from Capacity) on the same line
  lcd.print("I:"); 
  
  // Move the cursor to where the Capacity value should go (column 14, row 0)
  // NOTE: This leaves very little space. You may need to adjust layout.
  lcd.setCursor(11, 0);
  lcd.print(currentSettingA, 2);
  lcd.setCursor(15, 0);
  lcd.print("A");
  // lcd.print(capacityAh, 1); // Print the value with 1 decimal place

  // --- Line 2: Iset (Current Setting) ---
  
  // Set the cursor to the first column (0) of the second row (1)
  lcd.setCursor(0, 1); 
  
  // Print "Capacity :"
  lcd.print("Capacity :");
  
  // Move the cursor to where the Capacity value should go (column 10, row 1)
  lcd.setCursor(10, 1);
  
  // Print the Capacity value with 1 decimal place
  lcd.print(capacityAh, 1);
  
  // Move cursor to the space after Capacity
  lcd.setCursor(14, 1);
  
  // Print 'Ah' unit
  lcd.print("Ah");

  // Since we ran out of space, we'll use the available characters on the second line:
  
  // Clear the display for the next frame or use the space for Iset.
  // Since you need three items, we'll try to fit two on Line 1 and one on Line 2, or alternate.
  
  // --- Alternative Layout for Iset ---
  /*
  // Clear the display for the next frame
  delay(2000);
  lcd.clear();
  
  // Set the cursor to the first column (0) of the first row (0)
  lcd.setCursor(0, 0);
  lcd.print("Iset :");
  lcd.setCursor(6, 0);
  lcd.print(currentSettingA, 2); // Print the value with 2 decimal places
  lcd.print("A");
  */
  /*if (cellNumber < 10) 
  {
    cellNumber++;
  }

  else
  {
    cellNumber = 1;
  }
*/
  if (capacityAh < 5.0) 
  {
    capacityAh = capacityAh + 0.1;
  }

   else
  {
    capacityAh = 0.5;
  }
/*
  if (currentSettingA < 5) 
  {
    currentSettingA = currentSettingA + 0.5;
  }

   else
  {
    currentSettingA = 0.5;
  }
 */
  delay(1000); // Wait for 1 second before updating the display
  // In a real application, you might use an event-driven approach instead of delay().
}

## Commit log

2025-12-26 V1.1 and V1.2
    [Assembly BOM V1.2.csv, BOM V1.1.csv, Cell Characterization Board V1.1.PrjPcb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]
2026-01-01 Fixed the V1.2 Assembly BOM and intial commit for firmware
    [Assembly BOM V1.2.csv, BOM V1.1.csv, Cell Characterization Board V1.1.PrjPcb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]
2026-01-01 Fixed the V1.2 Assembly BOM and intial commit for firmware (auto) (auto)
    [Cell Characterization Board V1_Final.PrjPcb]
2026-01-01 File Rearrangement
    [Assembly BOM V1.2.csv, Buck and LDO.SchDoc, Cell Characterization Board V1.2.SchDoc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]
2026-01-04 Final Design with Notes and Hierarchial sheets and errors fixed
    [Assembly BOM V1.2.csv, Buck and LDO.SchDoc, Cell Characterization Board V1.2.SchDoc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]
2026-01-04 Update Cell Monitoring.SchDoc
    [Cell Monitoring.SchDoc]
2026-02-27 Update relay isolation description in README
2026-02-28 V2 initial commit
    [Buck and LDO.SchDoc, Cell Characterization Board V1.2.PcbDoc, Cell Characterization Board V1.PrjPcb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]
2026-03-01 Removed V1 files from V2
    [Pick Place for Cell Characterization Board V1.2.csv]
